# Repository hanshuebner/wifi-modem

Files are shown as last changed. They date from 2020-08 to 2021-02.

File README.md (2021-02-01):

# WiFi modem based on Zimodem

This project contains a PCB to turn a ESP-12F microcontroller into a
standalone WiFi modem with status LEDs and a RS-232 interface.  It is
designed to use [Zimodem](https://github.com/bozimmerman/Zimodem) as
firmware.

**Please do not use this PCB at this points.  There are bugs in it that
make it non-functional and I did not find the time to debug it yet.**

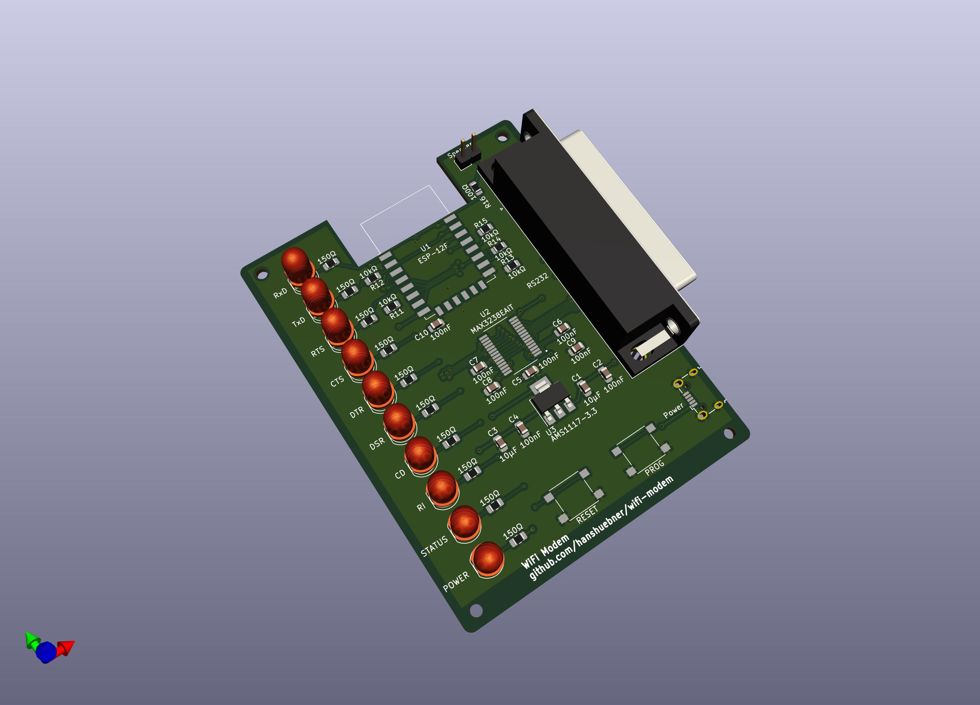
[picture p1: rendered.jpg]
Rendered PCB


[schematics](schematic.pdf)

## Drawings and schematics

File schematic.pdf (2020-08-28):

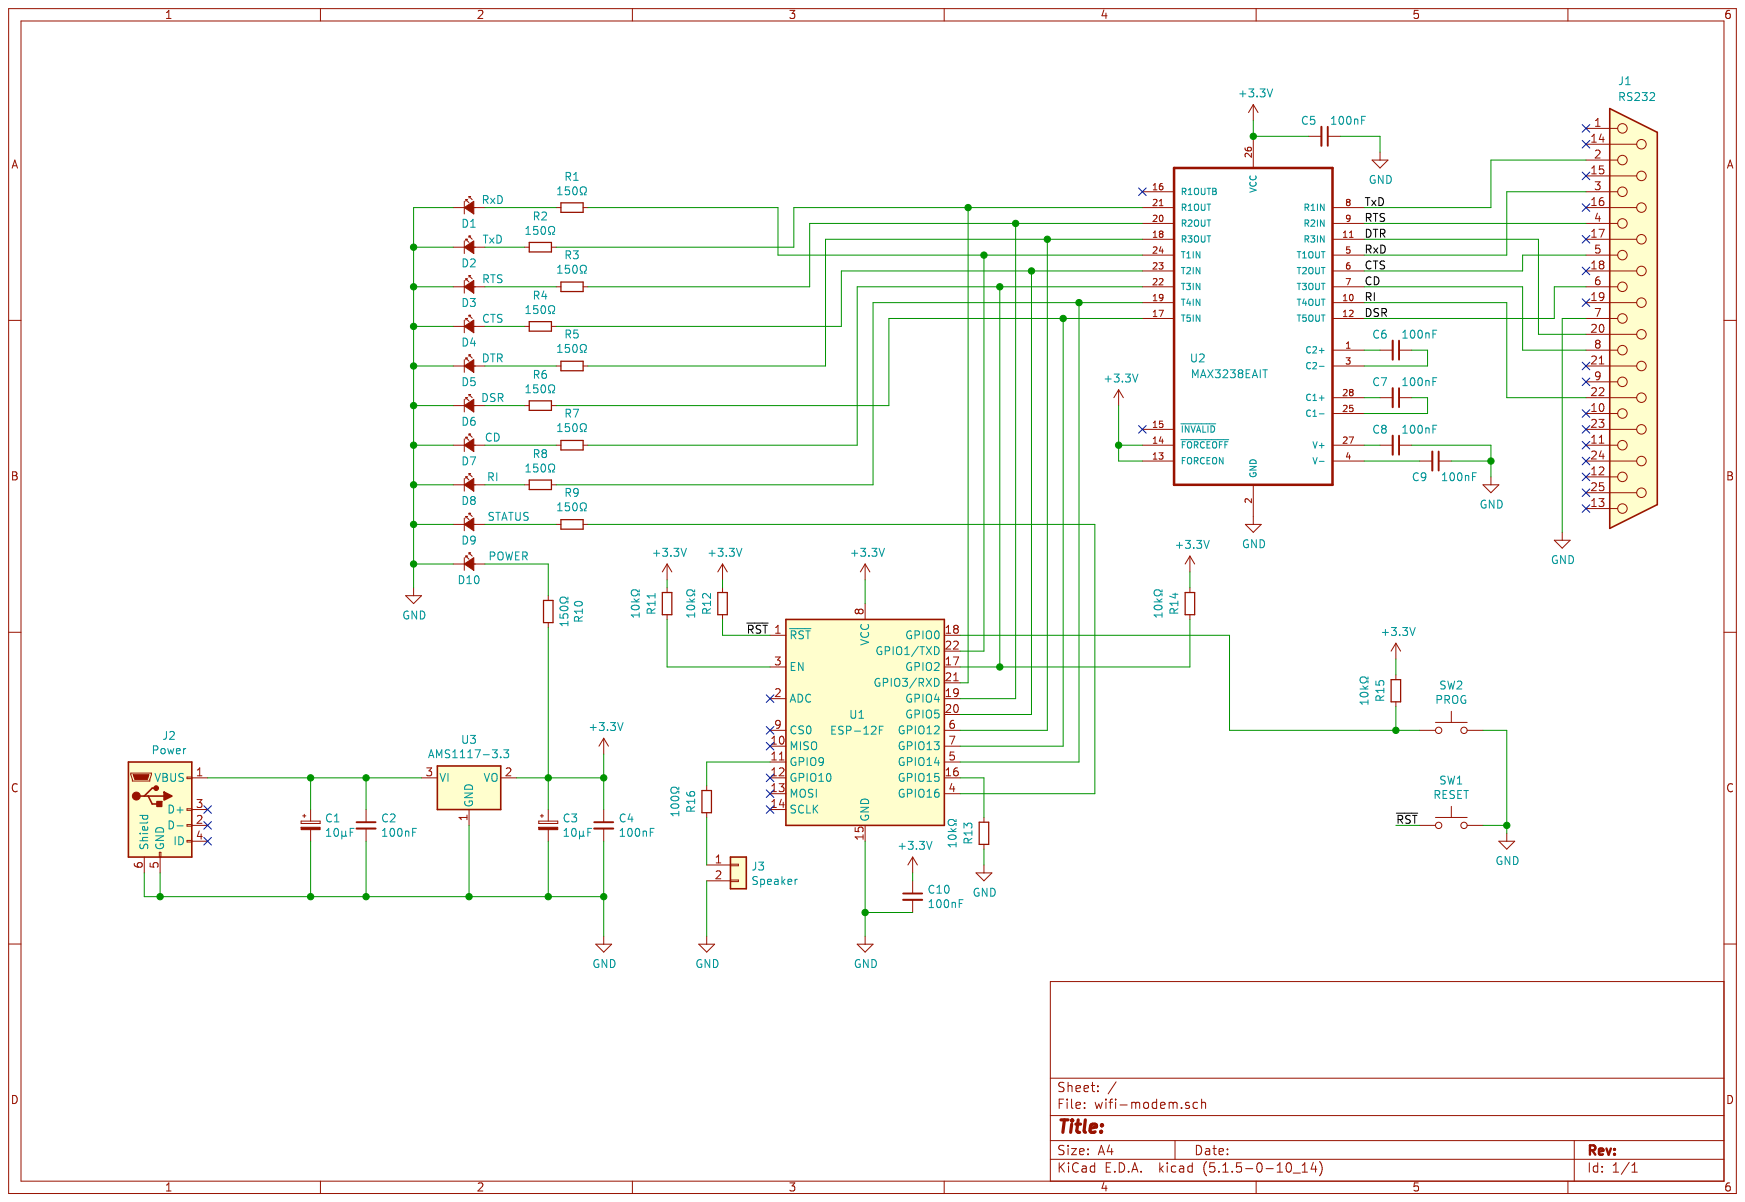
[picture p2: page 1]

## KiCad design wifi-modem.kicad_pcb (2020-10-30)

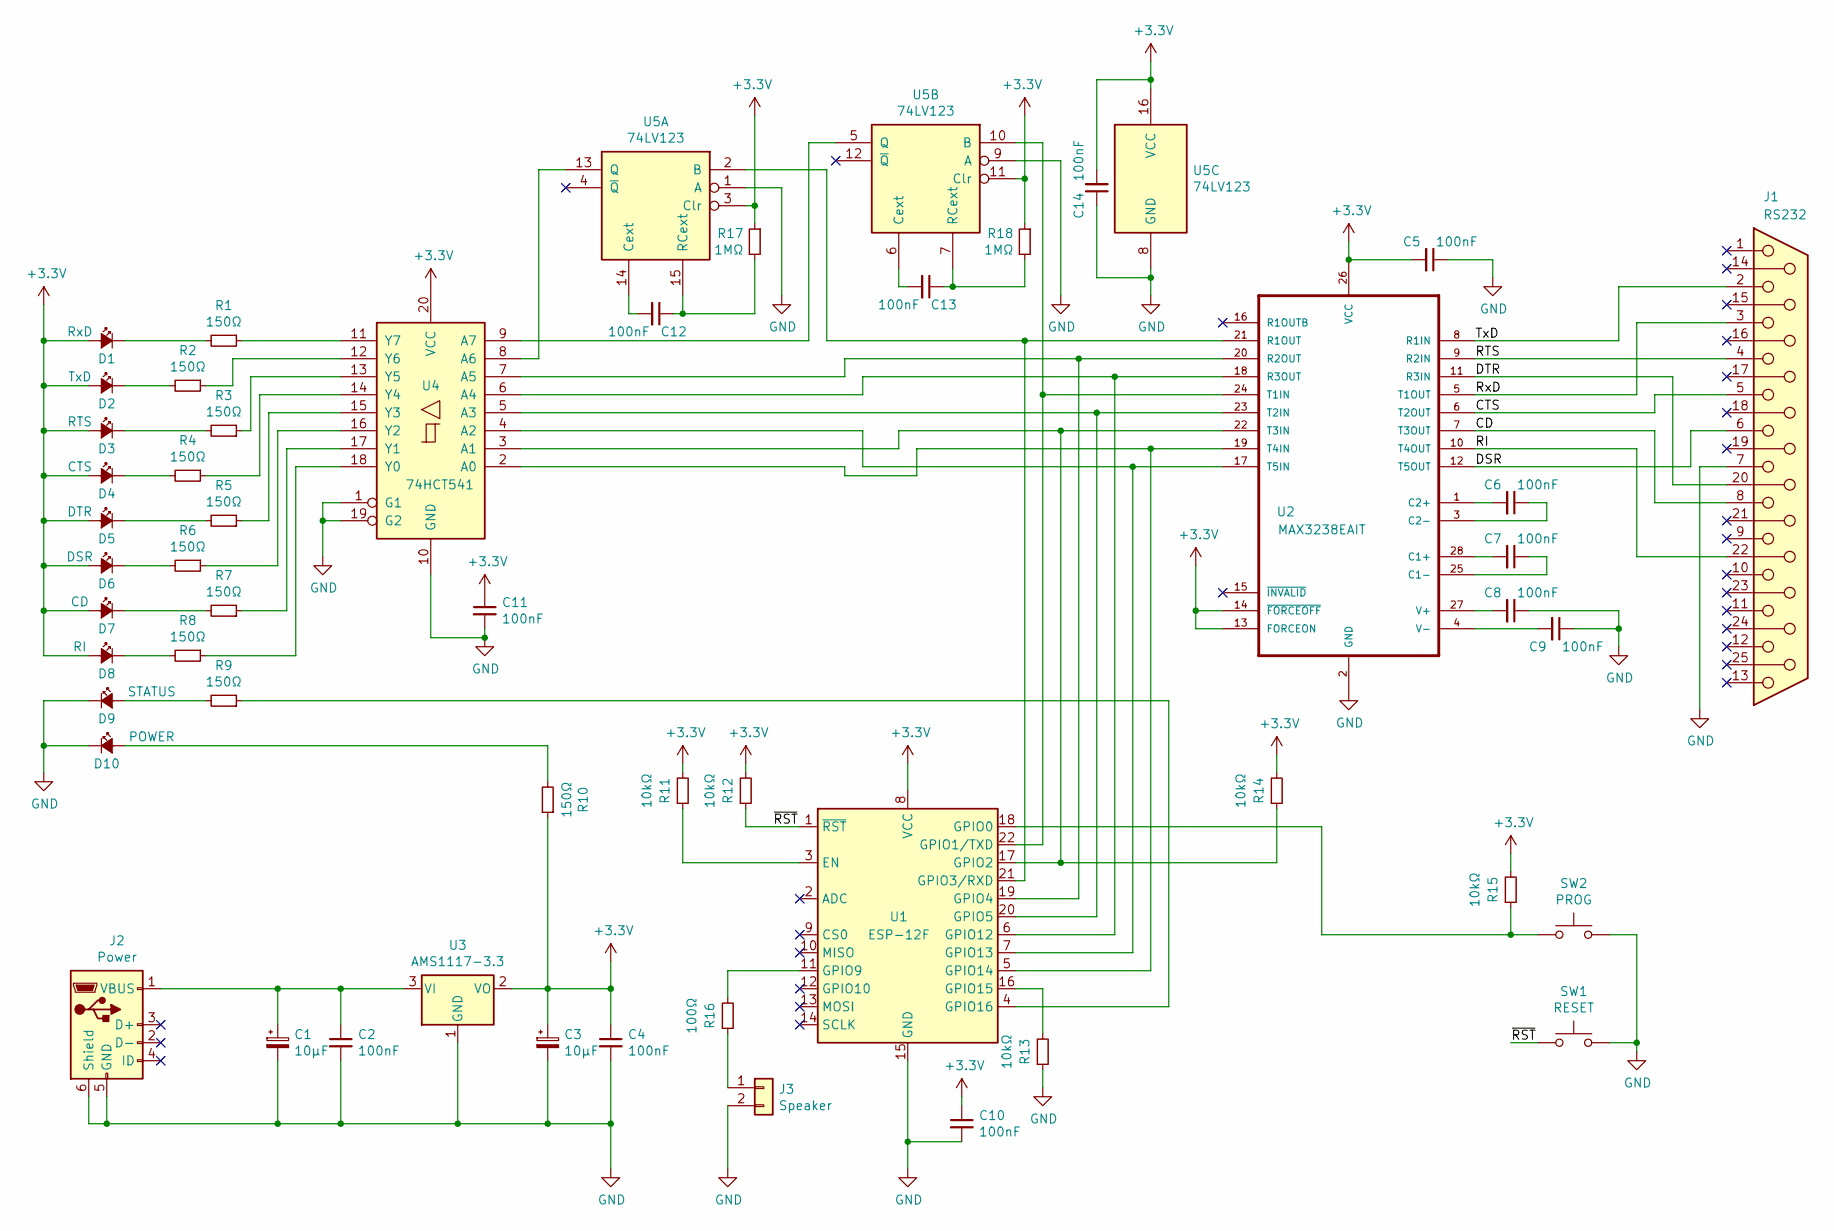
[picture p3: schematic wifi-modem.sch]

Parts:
C1, C3: 10µF; C_0805_2012Metric_Pad1.15x1.40mm_HandSolder
C2, C4, C5, C6, C7, C8, C9, C10, C11, C12, C13, C14: 100nF; C_0805_2012Metric_Pad1.15x1.40mm_HandSolder
D1: RxD; LED_D5.0mm
D2: TxD; LED_D5.0mm
D3: RTS; LED_D5.0mm
D4: CTS; LED_D5.0mm
D5: DTR; LED_D5.0mm
D6: DSR; LED_D5.0mm
D7: CD; LED_D5.0mm
D8: RI; LED_D5.0mm
D9: STATUS; LED_D5.0mm
D10: POWER; LED_D5.0mm
J1: RS232; DSUB-25_Female_Horizontal_P2.77x2.84mm_EdgePinOffset7.70mm_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
J2: Power; USB_Micro-B_Wuerth_629105150521
J3: Speaker; PinHeader_1x02_P2.54mm_Vertical
R1, R2, R3, R4, R5, R6, R7, R8, R9, R10: 150Ω; R_0805_2012Metric_Pad1.15x1.40mm_HandSolder
R11, R12, R13, R14, R15: 10kΩ; R_0805_2012Metric_Pad1.15x1.40mm_HandSolder
R16: 100Ω; R_0805_2012Metric_Pad1.15x1.40mm_HandSolder
R17, R18: 1MΩ; R_0805_2012Metric_Pad1.15x1.40mm_HandSolder
SW1: RESET; SW_Push_1P1T_NO_6x6mm_H9.5mm
SW2: PROG; SW_Push_1P1T_NO_6x6mm_H9.5mm
U1: ESP-12F; ESP-12E
U2: MAX3238EAIT; SOP65P777X199-28N
U3: AMS1117-3.3; SOT-223-3_TabPin2
U4: 74HCT541; TSSOP-20_4.4x6.5mm_P0.65mm
U5: 74LV123; TSSOP-16_4.4x5mm_P0.65mm

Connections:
+3V3: C3.1, C4.1, C5.2, C10.1, C11.1, C14.2, D1.2 (A), D2.2 (A), D3.2 (A), D4.2 (A), D5.2 (A), D6.2 (A), D7.2 (A), D8.2 (A), R10.1, R11.2, R12.2, R14.2, R15.2, R17.1, R18.1, U1.8 (VCC), U2.13 (FORCEON), U2.14 (~FORCEOFF~), U2.26 (VCC), U3.2 (VO), U4.20 (VCC), U5.3 (Clr), U5.11 (Clr), U5.16 (VCC)
/CD: J1.8, U2.7 (T3OUT)
/CTS: J1.5, U2.6 (T2OUT)
/DSR: J1.6, U2.12 (T5OUT)
/DTR: J1.20, U2.11 (R3IN)
/RI: J1.22, U2.10 (T4OUT)
/RTS: J1.4, U2.9 (R2IN)
/RxD: J1.3, U2.5 (T1OUT)
/TxD: J1.2, U2.8 (R1IN)
/~RST: R12.1, SW1.1, U1.1 (~RST)
GND: C1.2, C2.2, C3.2, C4.2, C5.1, C8.1, C9.1, C10.2, C11.2, C14.1, D9.1 (K), D10.1 (K), J1.7, J2.5 (GND), J2.6 (Shield), J3.2, R13.1, SW1.2, SW2.2, U1.15 (GND), U2.2 (GND), U3.1 (GND), U4.1 (G1), U4.10 (GND), U4.19 (G2), U5.1 (A), U5.8 (GND), U5.9 (A)
unnamed: C1.1, C2.1, J2.1 (VBUS), U3.3 (VI)
unnamed: C6.1, U2.3 (C2-)
unnamed: C6.2, U2.1 (C2+)
unnamed: C7.1, U2.25 (C1-)
unnamed: C7.2, U2.28 (C1+)
unnamed: C8.2, U2.27 (V+)
unnamed: C9.2, U2.4 (V-)
unnamed: C12.1, R17.2, U5.15 (RCext)
unnamed: C12.2, U5.14 (Cext)
unnamed: C13.1, R18.2, U5.7 (RCext)
unnamed: C13.2, U5.6 (Cext)
unnamed: D1.1 (K), R1.2
unnamed: D2.1 (K), R2.2
unnamed: D3.1 (K), R3.2
unnamed: D4.1 (K), R4.2
unnamed: D5.1 (K), R5.2
unnamed: D6.1 (K), R6.2
unnamed: D7.1 (K), R7.2
unnamed: D8.1 (K), R8.2
unnamed: D9.2 (A), R9.2
unnamed: D10.2 (A), R10.2
unnamed: J3.1, R16.1
unnamed: R1.1, U4.11 (Y7)
unnamed: R2.1, U4.12 (Y6)
unnamed: R3.1, U4.13 (Y5)
unnamed: R4.1, U4.14 (Y4)
unnamed: R5.1, U4.15 (Y3)
unnamed: R6.1, U4.16 (Y2)
unnamed: R7.1, U4.17 (Y1)
unnamed: R8.1, U4.18 (Y0)
unnamed: R9.1, U1.4 (GPIO16)
unnamed: R11.1, U1.3 (EN)
unnamed: R13.2, U1.16 (GPIO15)
unnamed: R14.1, U1.17 (GPIO2), U2.22 (T3IN), U4.3 (A1)
unnamed: R15.1, SW2.1, U1.18 (GPIO0)
unnamed: R16.2, U1.11 (GPIO9)
unnamed: U1.5 (GPIO14), U2.19 (T4IN), U4.2 (A0)
unnamed: U1.6 (GPIO12), U2.18 (R3OUT), U4.6 (A4)
unnamed: U1.7 (GPIO13), U2.17 (T5IN), U4.4 (A2)
unnamed: U1.19 (GPIO4), U2.20 (R2OUT), U4.7 (A5)
unnamed: U1.20 (GPIO5), U2.23 (T2IN), U4.5 (A3)
unnamed: U1.21 (GPIO3/RXD), U2.21 (R1OUT), U5.2 (B)
unnamed: U1.22 (GPIO1/TXD), U2.24 (T1IN), U5.10 (B)
unnamed: U4.8 (A6), U5.13 (Q)
unnamed: U4.9 (A7), U5.5 (Q)

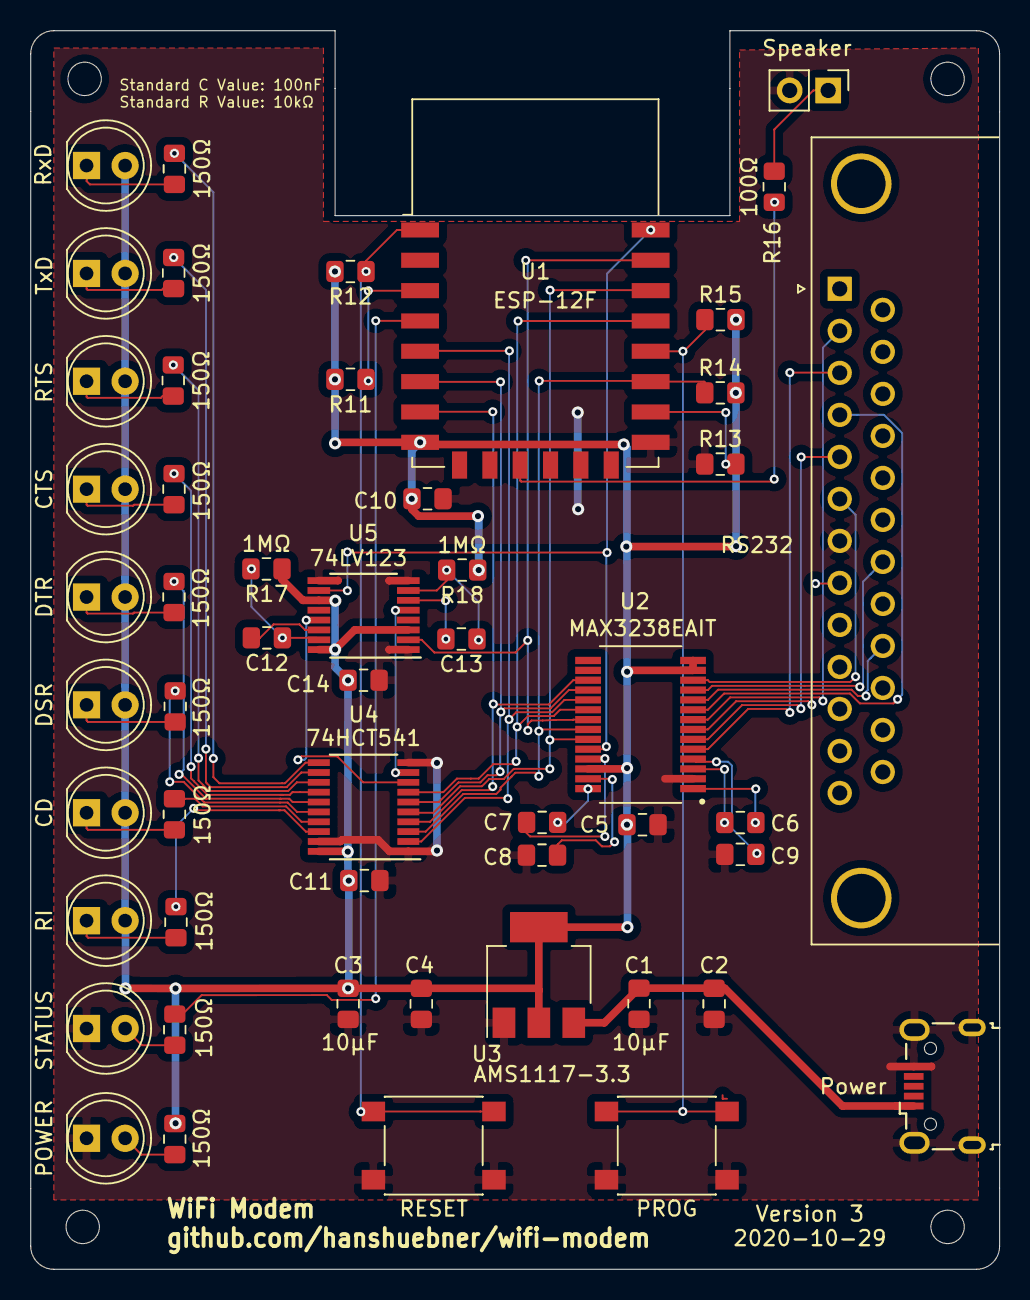
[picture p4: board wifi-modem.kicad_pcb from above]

Board: 2 copper layers, 63.9 x 81.7 mm, 52 parts (0 on the bottom side), 56 nets.

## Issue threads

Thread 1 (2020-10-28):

U4 Pin 19 not connected

hanshuebner, 2020-10-28:
Needs to connect to ground

hanshuebner, 2020-10-30:
Fixed in V3

Closed 2020-10-30.

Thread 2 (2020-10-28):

LEDs should connect to +5V, not GND

hanshuebner, 2020-10-28:
So that they light up when the signal is active

hanshuebner, 2020-10-30:
Fixed in V3

Closed 2020-10-30.

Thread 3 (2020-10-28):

Add monoflop to LEDs on data lines

hanshuebner, 2020-10-28:
So that they blink longer

hanshuebner, 2020-10-30:
Fixed in V3

Closed 2020-10-30.

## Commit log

2020-08-28 Layout redone
    [wifi-modem.kicad_pcb]
2020-08-28 Fixed connectors, added Speaker, made larger
    [wifi-modem.kicad_pcb, wifi-modem.sch]
2020-08-28 Fix swapped RX/TX lines
    [wifi-modem.kicad_pcb, wifi-modem.sch]
2020-08-28 V1 sent to JLCPCB
    [wifi-modem-B_Cu.gbr, wifi-modem-B_Mask.gbr, wifi-modem-B_Paste.gbr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]
2020-08-28 Sent to JLCPCB
    [wifi-modem.kicad_pcb]
2020-10-04 Added LED drivers
    [wifi-modem-B_Cu.gbr, wifi-modem-B_Mask.gbr, wifi-modem-B_Paste.gbr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]
2020-10-30 PCB Version 3
    [wifi-modem-B_Cu.gbr, wifi-modem-B_Mask.gbr, wifi-modem-B_Paste.gbr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]
